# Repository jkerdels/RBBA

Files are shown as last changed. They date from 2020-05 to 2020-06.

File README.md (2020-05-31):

# RBBA
resuscitator-based breathing assistance

This project explores the idea of building a breathing assistance system based on a resuscitator, which is safe enough for actual usage. This includes the use of sensors to limit the pressure supplied to a recipient and a calibration procedure that allows the system to estimate the volume of air given. In addition, the device should be printable on affordable, low-end 3D printers and use only hardware parts that are widely available. Likewise, the electronics involved should be as minimal as possible, easy to program, and adaptable to one's needs.

## Current Status

There exists a hardware prototype including a control-box that houses all the electronics and an external pressure sensor. Furthermore, all basic software components are implemented and ready to be used for the user-end part of the code (which is still incomplete).

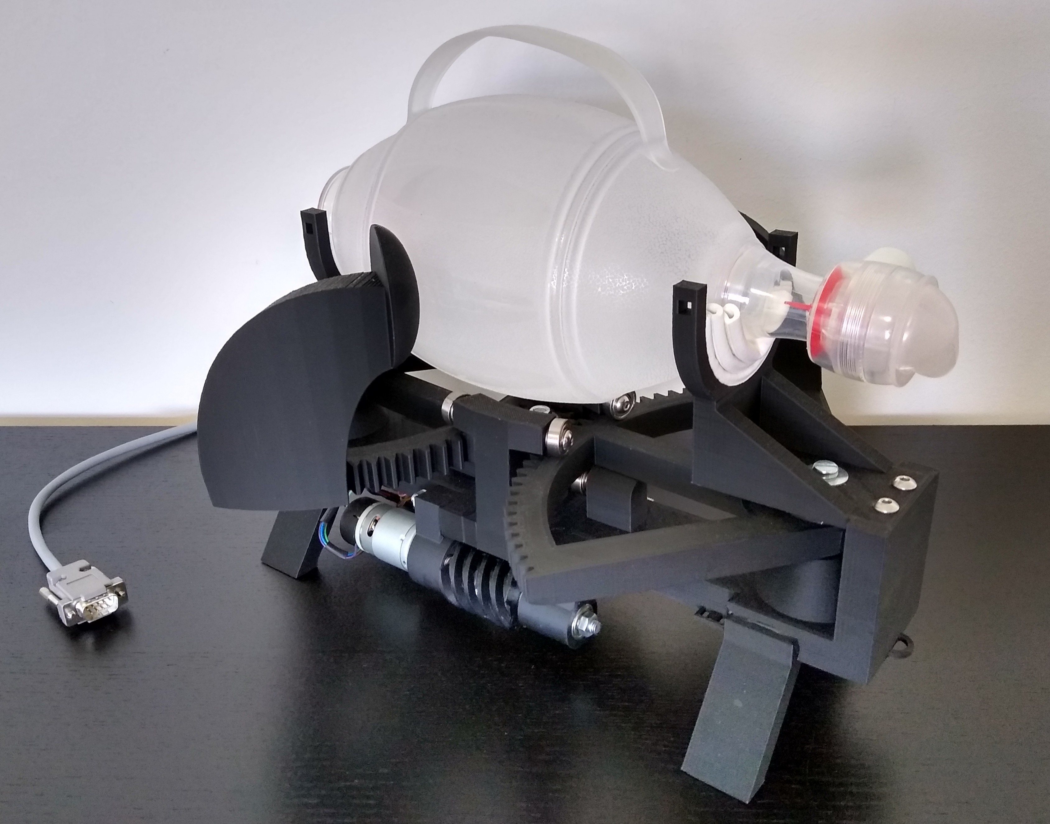
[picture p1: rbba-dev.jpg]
device_photo device prototype

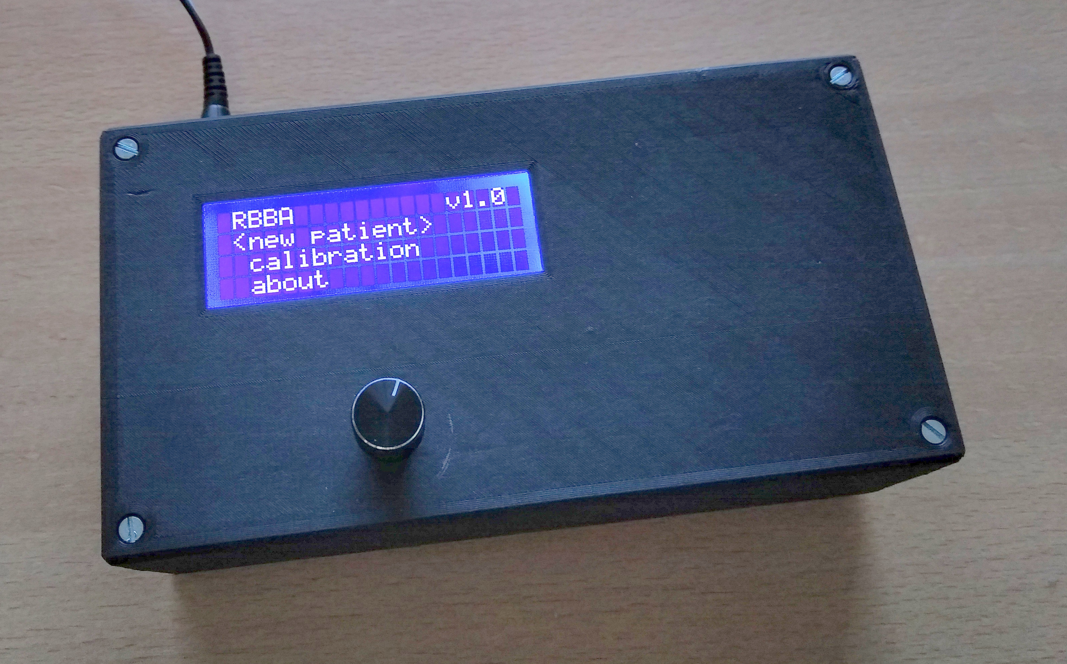
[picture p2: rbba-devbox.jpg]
controlbox_photo control box prototype

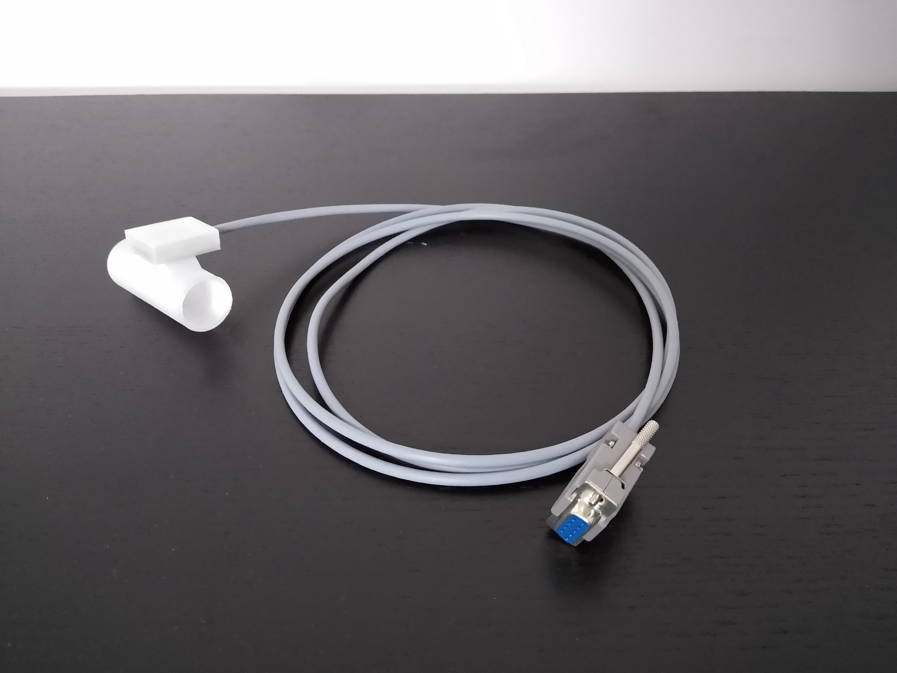
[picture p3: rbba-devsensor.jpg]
sensor_photo pressure sensor prototype


## Geometry

The geometry of the hardware was modeled in OpenSCAD. This way, it is relatively easy to adapt the geometry, e.g., to work well with a particular 3D-printer. In addition, using OpenSCAD allows to automate the generation of all stl-files via a simple command line script.

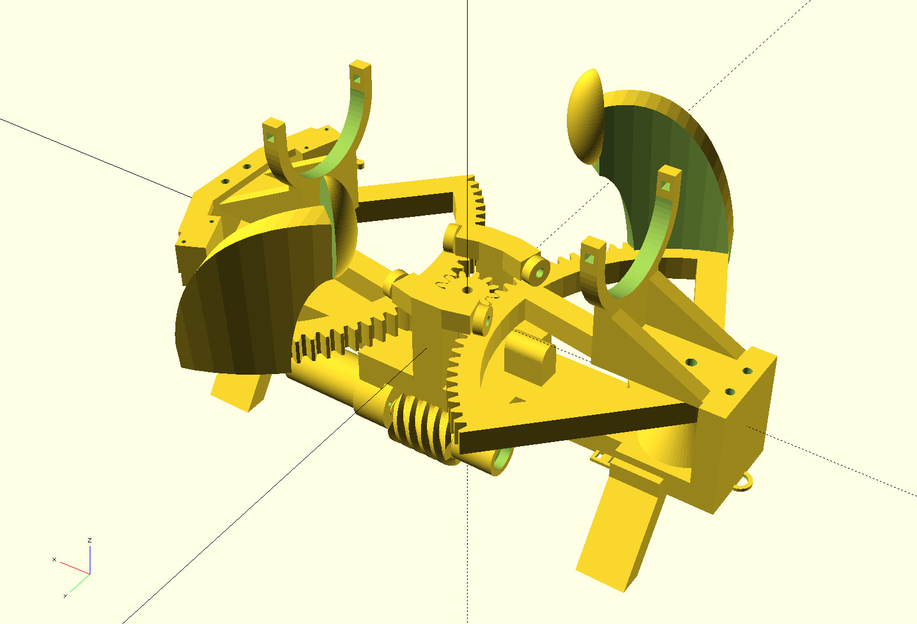
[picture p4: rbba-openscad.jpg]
parametric_geometry device geometry


## Electronics & Code

The electronics are based on the Arduino platform in order to make the code and hardware as accessible as possible. The arduino project does not rely on external libraries and brings everything with it to, e.g., read out sensors or write messages to the output display. The main board used is an Arduino Nano compatible device. Additional modules include the BMP280 pressure sensor, a L298N motor driver, a HD44780 display with an I2C-Driver (FC-113), and a rotary encoder input dial.

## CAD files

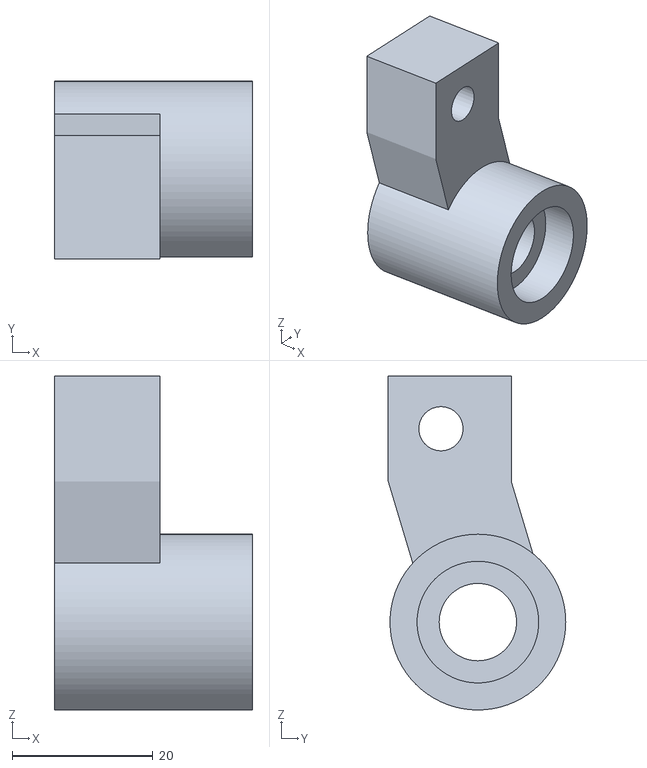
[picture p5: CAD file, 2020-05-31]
openscad/stl/wormgearmount.stl
28.2 x 25.2 x 47.5

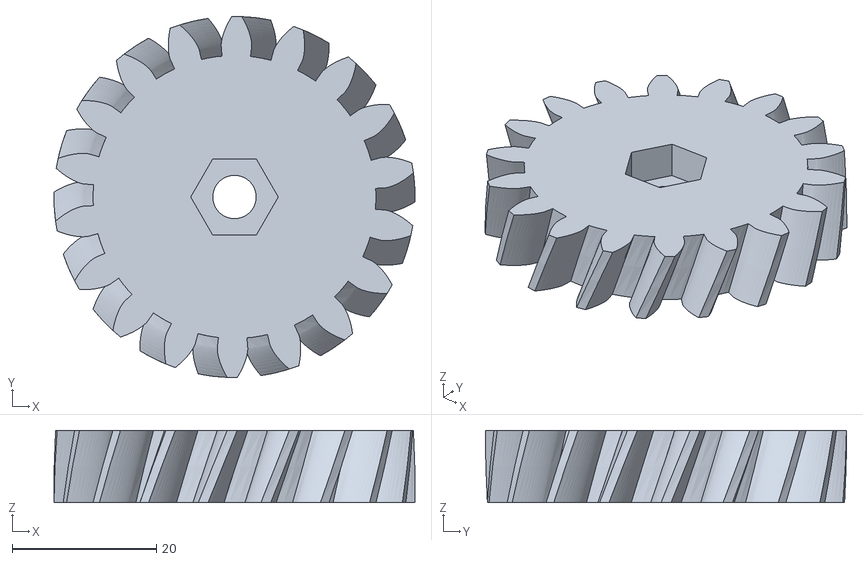
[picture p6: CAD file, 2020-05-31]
openscad/stl/motor_gear_1.stl
50.0 x 50.0 x 10.0

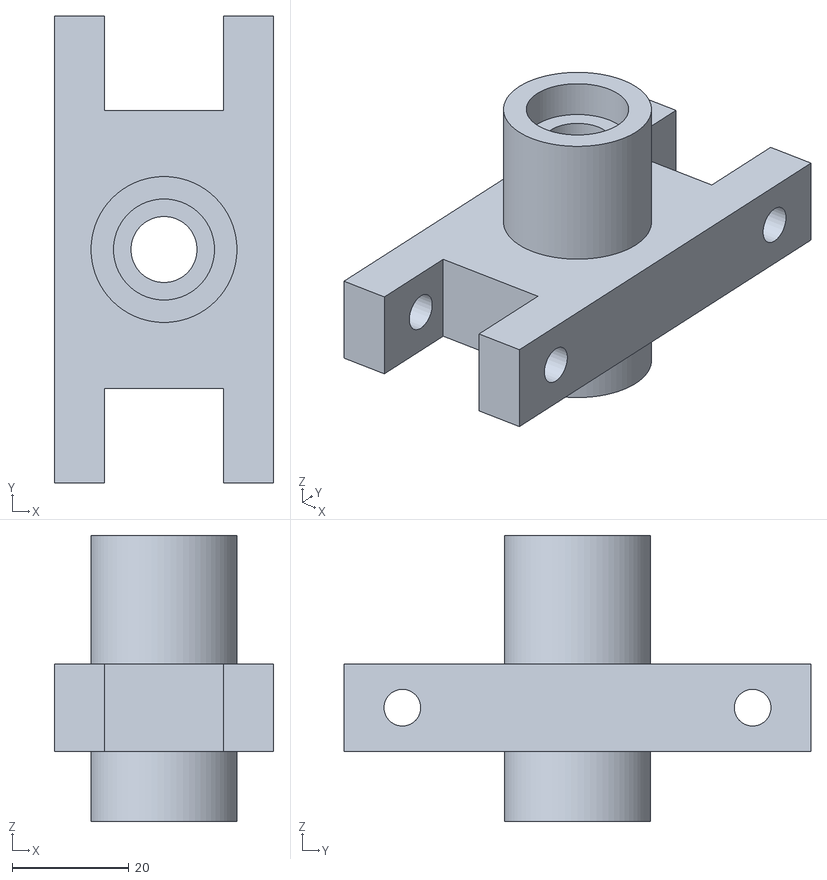
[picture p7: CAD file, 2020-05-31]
openscad/stl/centermount.stl
37.6 x 80.0 x 49.0

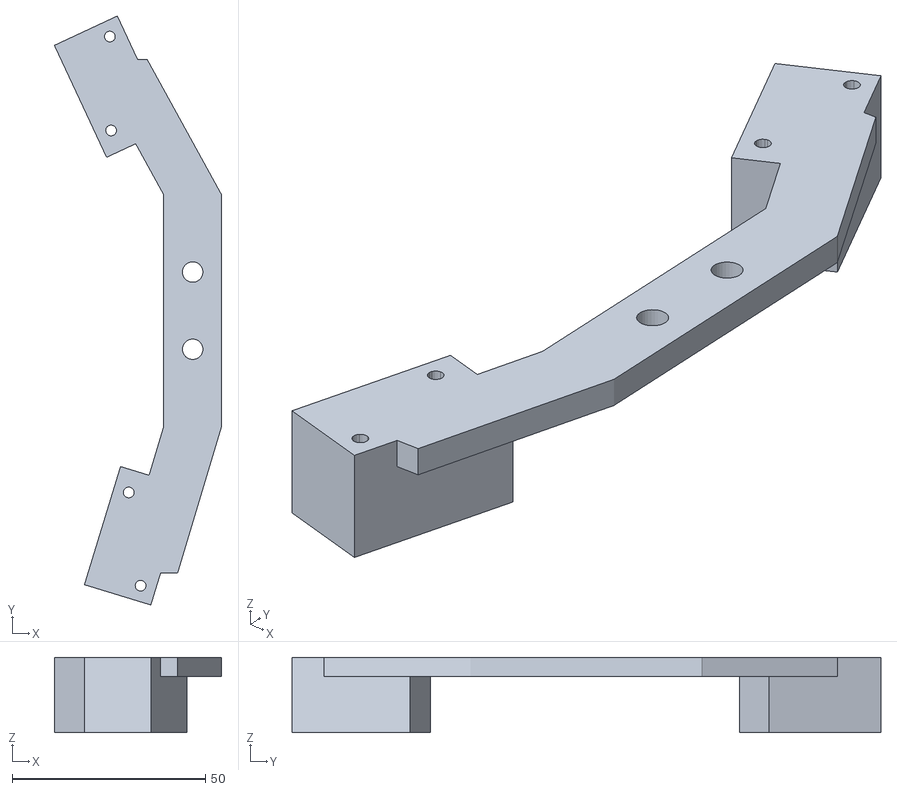
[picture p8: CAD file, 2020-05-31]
openscad/stl/switchmount.stl
43.3 x 152.6 x 19.5

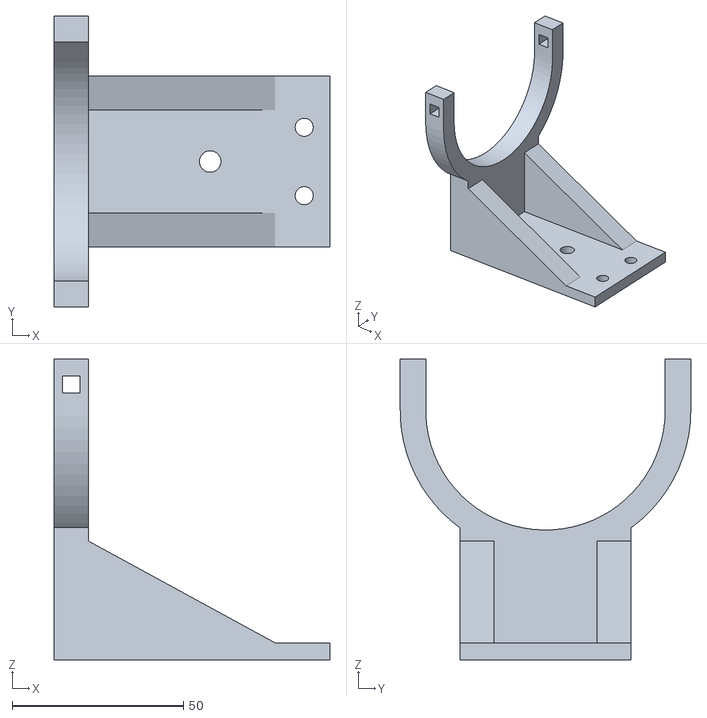
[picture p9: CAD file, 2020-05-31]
openscad/stl/bagmount.stl
80.6 x 85.0 x 88.0

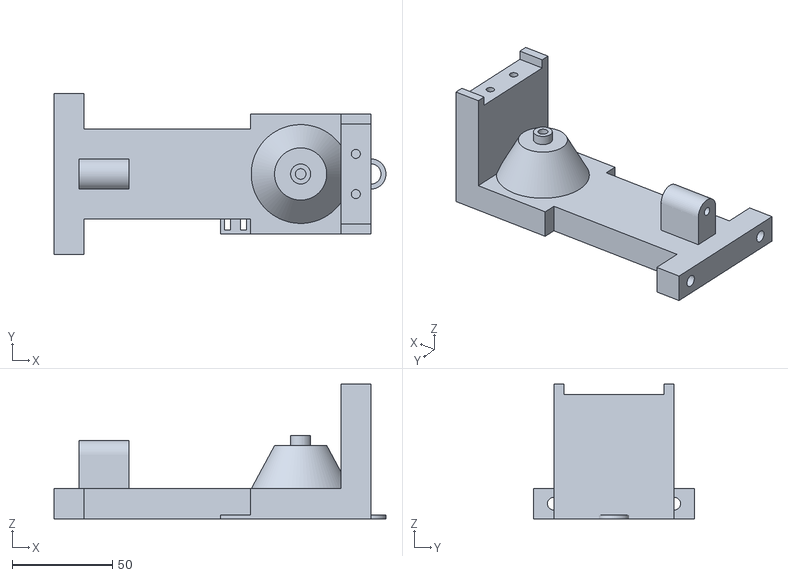
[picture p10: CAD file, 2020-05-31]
openscad/stl/gear_base.stl
165.3 x 80.0 x 67.0

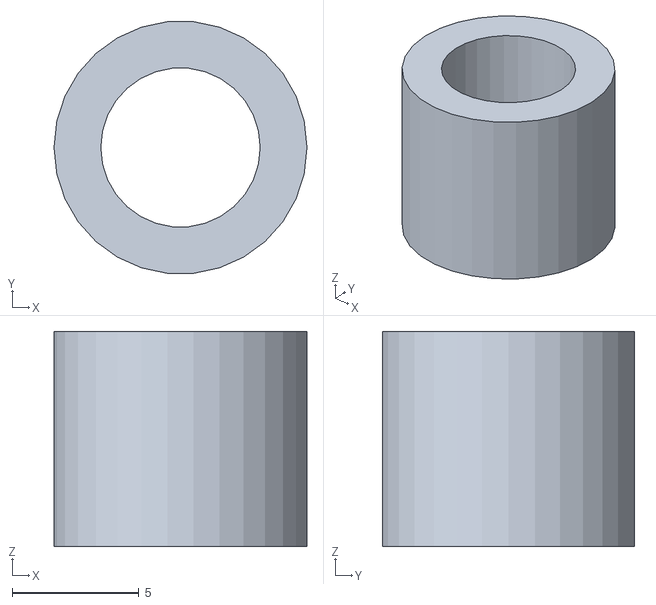
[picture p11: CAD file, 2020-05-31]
openscad/stl/bagmount_spacer.stl
10.0 x 9.95 x 8.50

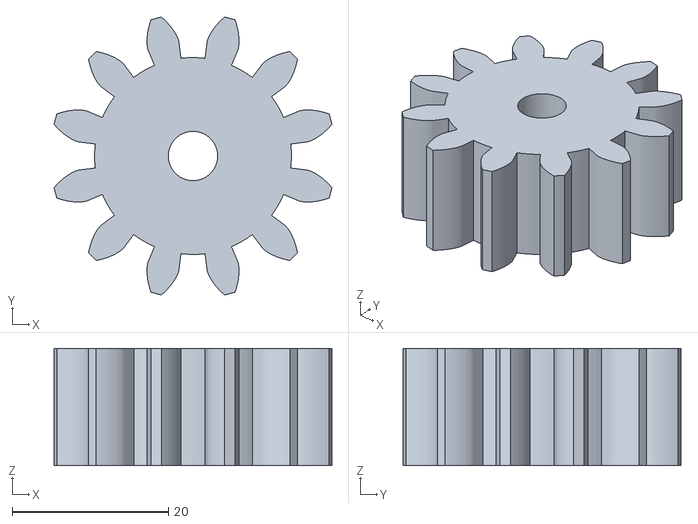
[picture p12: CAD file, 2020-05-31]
openscad/stl/drive_gear.stl
35.5 x 35.5 x 15.0

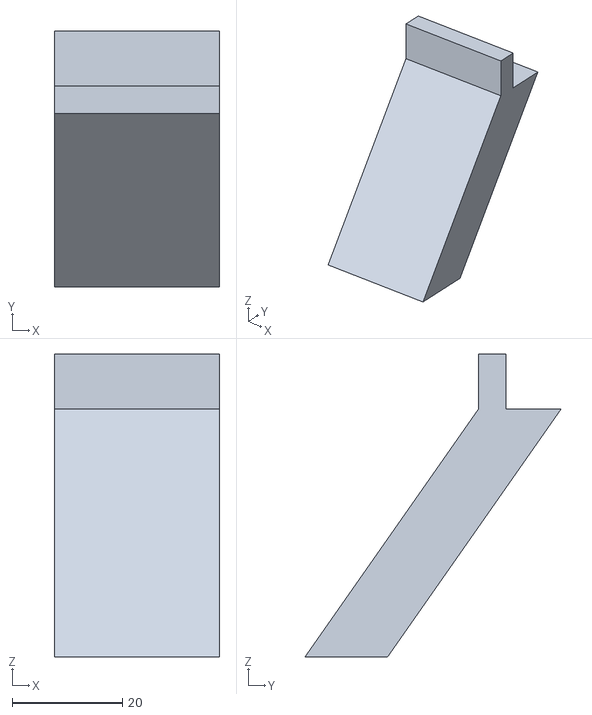
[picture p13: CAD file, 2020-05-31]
openscad/stl/leg.stl
30.0 x 46.5 x 55.0

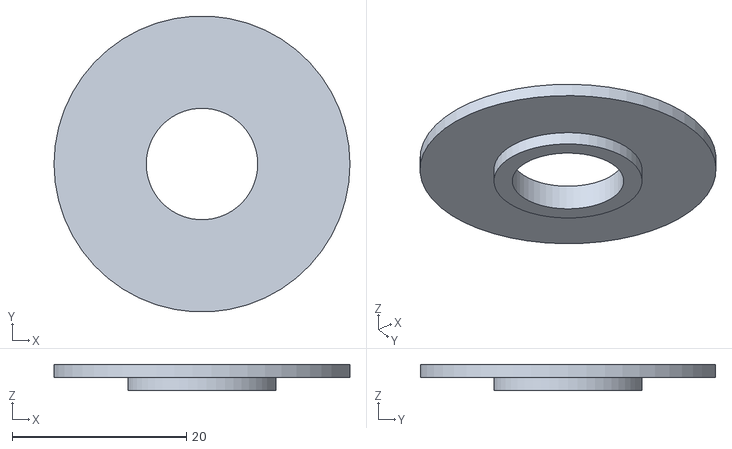
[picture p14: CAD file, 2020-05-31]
openscad/stl/gear_plug.stl
34.0 x 33.9 x 3.00

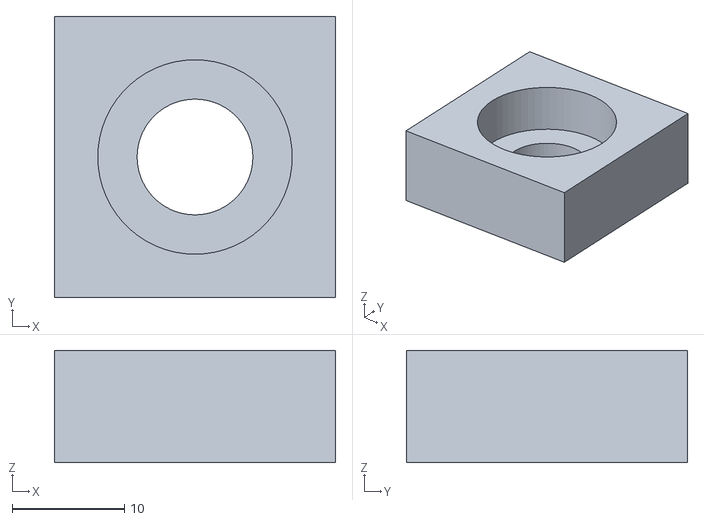
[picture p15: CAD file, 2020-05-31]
openscad/stl/calibration.stl
25.0 x 25.0 x 10.0

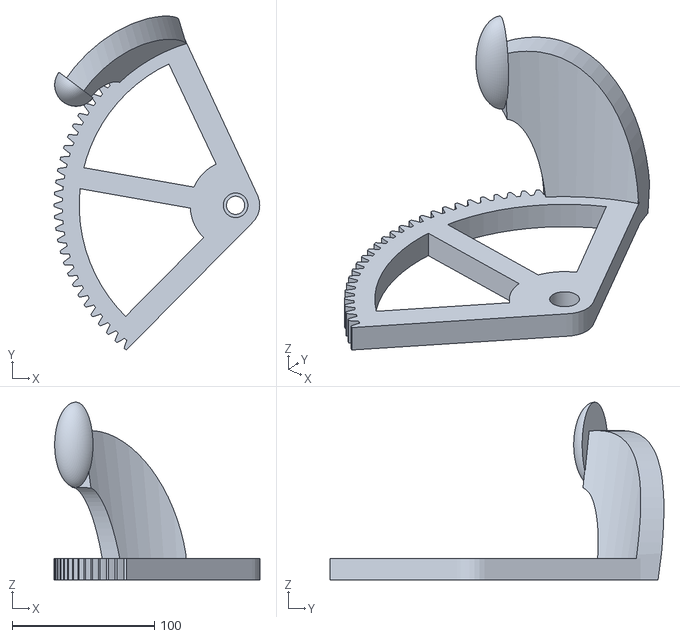
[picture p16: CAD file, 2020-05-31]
openscad/stl/gear.stl
144.6 x 235.0 x 124.9

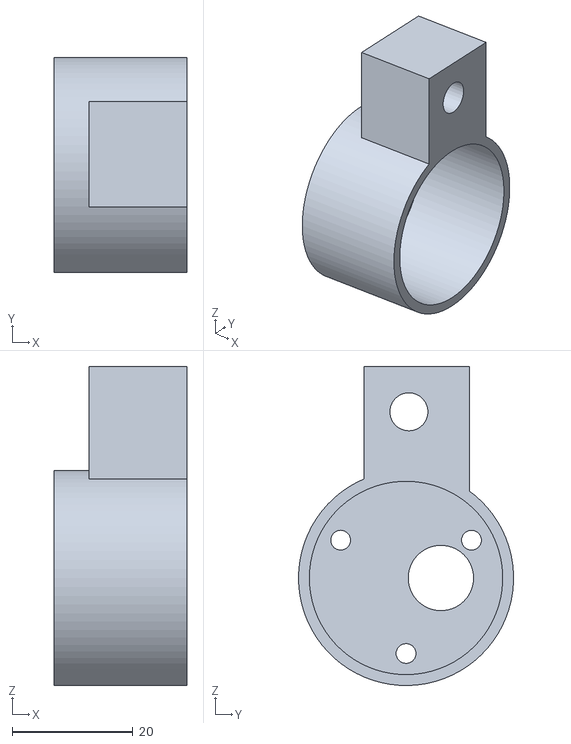
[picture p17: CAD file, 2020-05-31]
openscad/stl/motormount.stl
22.0 x 35.6 x 52.8

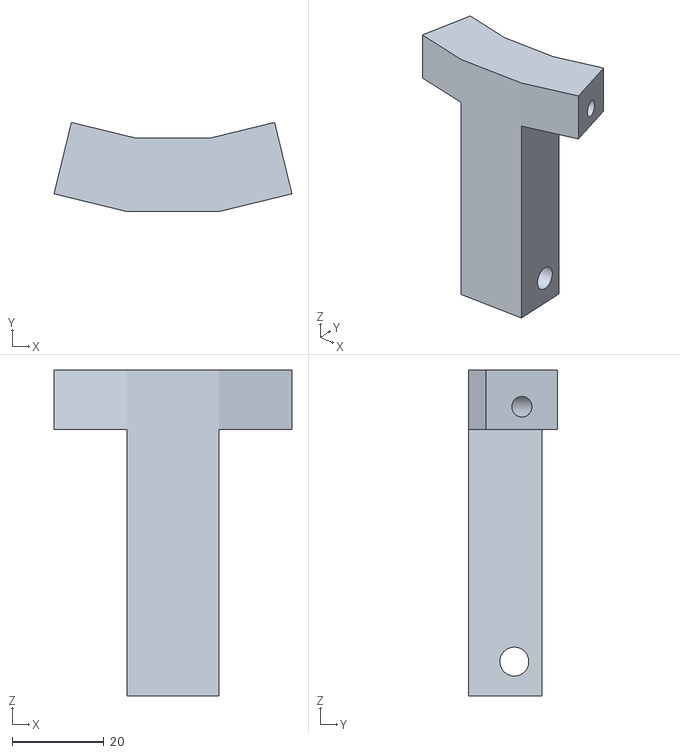
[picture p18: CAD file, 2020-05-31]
openscad/stl/bearingmount.stl
51.8 x 19.4 x 71.0

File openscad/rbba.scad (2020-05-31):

/* rbba.scad 

    3D geometry of a 3D-printable breathing assistance system that utilizes
    a standard resuscitator.
    
    The different parts can be selected via the render_ctl variable by 
    setting it to the available render_ctl options (see below). Instead,
    all parts can be rendered via the render_stl.sh script.
    
    The 3D geometry defined here uses the OpenSCAD-Library "Getriebe.scad"
    by Dr Jörg Janssen in Version 2.3 . The library is contained in the
    3rd-party folder and should be put into the library-folder of your
    OpenSCAD installation. You can find the library folder by clicking on
    "File->Show Library Folder..." in OpenSCAD.

    The device consists of three major parts: two identical outer parts
    and a center piece that may has to be adapted to the particular 
    requirements of the geared motor used.
    
    To adjust the model to your printer, the variable "hole_extra" allows
    you to tweak the size of negative shapes in the model. There is a 
    calibration piece that can be selected with render_ctl = rc_calibration;
    You should be able to put a 17mm bearing snugly into the hole of the
    calibration piece. Please adjust the hole_extra variable until that is
    the case.
    
    The bearings used here are 17mm outside diameter, 6mm inner diameter, 
    and 6mm height. If you want to use bearings with slightly different
    dimensions you can adjust the variables bearing_outer, bearing_inner,
    and bearing_height.
*/
use <Getriebe.scad>;

hole_extra = 0.3;

pr_diam   = 250;
pr_zaehne = 96;
pr_modul  = pr_diam/pr_zaehne;
pr_breite = 15;
pr_loch   = 17;

bag_dia = 130;

hole_drive = 5;
notch_drive = 4;
teeth_drive = 12;
diam_drive = pr_modul * teeth_drive;

bearing_outer  = 17;
bearing_inner  = 6;
bearing_height = 6;

bearing_offset = 0.5;

//gear_angle = 27;
gear_angle = 0;

motor_mount_width = 35.6;
motor_mount_extra = 2;

// render_ctl options: 
rc_all             = "all";
rc_calibration     = "calibration";
rc_gear            = "gear";
rc_gear_base       = "gear_base";
rc_gear_plug       = "gear_plug";
rc_drive_gear      = "drive_gear";
rc_motormount      = "motormount";
rc_bearingmount    = "bearingmount";
rc_bagmount        = "bagmount";
rc_bagmount_spacer = "bagmount_spacer";
rc_leg             = "leg";
rc_switchmount     = "switchmount";
rc_motor_gear1     = "motor_gear1";
rc_motor_gear2     = "motor_gear2";
rc_centermount     = "centermount";
rc_wormgearmount   = "wormgearmount";

render_ctl = rc_all;

module bearing() {
    color("silver")
    difference(){
        cylinder(d=bearing_outer,h=bearing_height,$fn=72);   
        translate([0,0,-1]) 
        cylinder(d=bearing_inner,h=bearing_height+2,$fn=30);
    }
}

module bearings() {    
    translate([diam_drive/2+10,0,0])
    translate([pr_diam/2-10,0,0])
    rotate([0,0,0])
    translate([-pr_diam/2+10,0,0])
    translate([-bearing_height/2,0,-bearing_outer/2])
    rotate([90,0,90])
    bearing();

    translate([pr_diam/2+diam_drive/2,0,pr_breite+bearing_outer/2])
    rotate([0,0,13.668])
    translate([-pr_diam/2,0,0])
    translate([6.5,0,0])
    rotate([90,0,90])
    bearing();

    mirror([1,0,0])
    translate([pr_diam/2+diam_drive/2,0,pr_breite+bearing_outer/2])
    rotate([0,0,13.668])
    translate([-pr_diam/2,0,0])
    translate([6.5,0,0])
    rotate([90,0,90])
    bearing();

    rotate([0,0,180]){
        translate([pr_diam/2+diam_drive/2,0,pr_breite+bearing_outer/2])
        rotate([0,0,13.668])
        translate([-pr_diam/2,0,0])
        translate([6.5,0,0])
        rotate([90,0,90])
        bearing();

        mirror([1,0,0])
        translate([pr_diam/2+diam_drive/2,0,pr_breite+bearing_outer/2])
        rotate([0,0,13.668])
        translate([-pr_diam/2,0,0])
        translate([6.5,0,0])
        rotate([90,0,90])
        bearing();
    }

    /*
    translate([diam_drive/2+10,0,0])
    translate([pr_diam/2-10,0,0])
    rotate([0,0,-30])
    translate([-pr_diam/2+10,0,0])
    translate([-bearing_height/2,0,-bearing_outer/2])
    rotate([90,0,90])
    bearing();

    translate([diam_drive/2+10,0,0])
    translate([pr_diam/2-10,0,0])
    rotate([0,0,30])
    translate([-pr_diam/2+10,0,0])
    translate([-bearing_height/2,0,-bearing_outer/2])
    rotate([90,0,90])
    bearing();
    */

}

module bag() {
    sphere(d=bag_dia,$fn=75);

    translate([0,5/2-100,0])
    rotate([90,0,0])
    cylinder(d=45,h=5);

    translate([0,5/2+90,0])
    rotate([90,0,0])
    cylinder(d=70,h=5);
}


module pusher_knob() {
    translate([0,0,0])
    rotate([0,90,0])
    difference(){
        scale([1,0.5,0.5])
        sphere(d=60,$fn=75);
        translate([-30,-30,0])
        cube([60,60,30]);        
    }    
}

module push_rod(){
    translate([0,-15/2,-30/2])
    cube([30,15,30]);

    translate([15,-15/2,-30-30/2])
    cube([15,15,30]);

    translate([15,-15/2,-85-30-30/2])
    cube([15,15,85]);
}

module drive_gear() {
        
    render()
    difference(){
        union(){
            stirnrad (pr_modul, teeth_drive, pr_breite, hole_drive+hole_extra, optimiert=false);

            rotate([0,0,180/teeth_drive])
            translate([-(hole_drive+hole_extra)/2,(hole_drive+hole_extra)/2-(hole_drive-notch_drive),0])
            cube([hole_drive+hole_extra,hole_drive+hole_extra/2,pr_breite]);
        }
        translate([0,0,-2.5])
        rotate([0,0,180/teeth_drive])
        translate([0,0,pr_breite/2]){
            rotate([270,0,0])
            cylinder(d=3+hole_extra,h=40,$fn=30);
            translate([-(5.5+hole_extra)/2,diam_drive/6,-(1.5+hole_extra)-1.8])
            cube([5.5+hole_extra,2.5+hole_extra,pr_breite/2+1.8+hole_extra+10]);
        }
    }
}

module drive_gear2() {
        
    render()
    difference(){
        union(){
            stirnrad (pr_modul, teeth_drive, pr_breite, 6+hole_extra, optimiert=false);
        }
        translate([0,0,-1])
        for(i = [0:60:359])
        rotate([0,0,i])
        translate([-(6+hole_extra-0.25)/2,-(10+hole_extra+0.2)/2,0])
        cube([6+hole_extra-0.25,10+hole_extra+0.2,5+1]);
    }
    
}

module gear_plug() {

    translate([0,0,pr_breite-1.5])
    difference(){
        cylinder(d=pr_loch,h=1.5,$fn=50);
        translate([0,0,-1])
        cylinder(d=pr_loch-4.5+hole_extra,h=3.5,$fn=50);
    }

    translate([0,0,pr_breite])
    difference(){
        cylinder(d=pr_loch*2,h=1.5,$fn=50);
        translate([0,0,-1])
        cylinder(d=pr_loch-4.5+hole_extra,h=3.5,$fn=50);
    }
    
}

module cake(angle){
    color("blue")
    difference(){
        cylinder(d=pr_diam-30,h=pr_breite+2,$fn=75);
        translate([-pr_diam/2,0,-1])
        cube([pr_diam,pr_diam/2,pr_breite+4]);
        rotate([0,0,angle])
        translate([-pr_diam/2,0,-1])
        cube([pr_diam,pr_diam/2,pr_breite+4]);
        translate([0,0,-1])
        cylinder(d=2*pr_loch+30,h=pr_breite+4,$fn=75);
    }
}

module gear(offset = false) {
    render()
    difference(){
        intersection(){
            rotate([0,0,offset ? 180/pr_zaehne : 0])
            stirnrad (pr_modul, pr_zaehne, pr_breite, pr_loch+hole_extra, optimiert=false);

            translate([0,0,-1])
            linear_extrude(height=pr_breite*2)
            minkowski(){
                union(){
                    rotate([0,0,115])
                    square([pr_diam/2+10,pr_diam/2+10]);
                    rotate([0,0,135.3])
                    square([pr_diam/2+10,pr_diam/2+10]);
                }
                circle(d=pr_loch*2);
            }
        }    
        translate([0,0,-1])
        rotate([0,0,135.3+90])
        cake(70);
    }
    
    rotate([0,0,170])
    translate([10,-15/2,0])
    cube([pr_diam/2-20,15,pr_breite]);
    
    difference(){
        cylinder(d=pr_loch+1,h=1.5,$fn=50);
        translate([0,0,-1])
        cylinder(d=pr_loch-4.5+hole_extra,h=3.5,$fn=50);
    }

    difference(){
        intersection(){
            difference(){
                translate([0,0,0])
                cylinder(d1=pr_diam+5+15,d2=pr_diam+5+15+diam_drive/2+13,h=bag_dia/2+5+20+pr_breite,$fn=75);

                translate([0,0,-1])
                cylinder(d1=pr_diam+5-30+7.5,d2=pr_diam+5-30+7.5+diam_drive/2+20,h=bag_dia/2+5+20+pr_breite+2,$fn=75);
                
                rotate([0,0,180-36.8])
                translate([-(pr_diam+50+diam_drive)/2,0,-1])
                cube([pr_diam+50+diam_drive,pr_diam/2+50+diam_drive,bag_dia/2+5+20+pr_breite+2]);

                rotate([0,0,287])
                translate([-(pr_diam+50+diam_drive)/2,0,-1])
                cube([pr_diam+50+diam_drive,pr_diam/2+50+diam_drive,bag_dia/2+5+20+pr_breite+2]);
            }    
            rotate([0,0,16.5])
            scale([0.7,1,1])
            translate([-105,0,0])
            rotate([270,0,0])
            cylinder(d=210,h=150,$fn=75);
        }
        rotate([0,0,43])
        scale([0.5,1,1.3])
        translate([-50,0,0])
        rotate([270,0,0])
        cylinder(d=100,h=150,$fn=75);
    }
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

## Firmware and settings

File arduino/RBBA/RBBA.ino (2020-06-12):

/* Overview:

This is the main file for the arduino part of the RBBA project.

To build your own RBBA it is not strictly necessary to have all the
exact same electronic parts as they are used here, i.e., this arduino
project serves more as an example of how one might control the device.

For all components that are used in this example code I did not use
any libraries but implemented everything from scratch. This had multiple
purposes: 1) If you use code in a medical device you should be familiar
with the code and the devices you use as much as possible. Using libraries
and electronic components "black box style" is (in my opinion) not a
good choice in that case. 2) You minimize dependencies on 3rd-party code
a lot, which makes the code much more self-contained and easier to use
for others. 3) There is an educational aspect in both writing the 
libraries myself and "seeing" that the apparent complexity of an 
electronic project with many components, different protocols, etc. is
actually manageable and not as hard as one might think.

This style starts with a configuration section where you can map the
pins used on your arduino board to the different components like the
motor controller or the encoder of the motor. Most pins used are general
purpose digital IO-pins. If the pin has to have some special abilities
it is noted via a comment.

Following the configuration section is an implementation section where
the different components of the program are instantiated as global
variables. Part of this section is the instantiation/definition of 
the user menu and multiple state machines that define the behavior
of the system. Both constructs make use of rather modern C++, e.g.,
using lambda functions to construct menu pages or define the code
that is run in a given state. This might seem a bit over-engineered
and a number of people will prefer the more simpler or "proven" approach
of switch-based state machines.

Finally, the arduino-typical setup and loop functions do little more
than putting all the previously defined puzzle-pieces together.

*/

#include <stdint.h>
#include <EEPROM.h>
#include "encoder.h"
#include "motor_control.h"
#include "soft_bmp280.h"
#include "soft_hd44780.h"
#include "lcd_menu.h"
#include "text_buffer.h"
#include "state_machine.h"
#include "string_constants.h"

// configuration
const uint8_t motor_enable_pin      = 3; // OC2B of timer2
const uint8_t motor_direction_pin_A = 4;
const uint8_t motor_direction_pin_B = 5;
const uint8_t end_stop_opened_pin   = 7;
const uint8_t end_stop_closed_pin   = 8;
const uint8_t motor_encoder_pin_A   = 2; // needs to be on an interrupt pin
const uint8_t motor_encoder_pin_B   = 6;

const uint8_t control_loop_delay = 20;

const uint8_t p1_slave_address = 0x77;
const uint8_t p1_scl_pin       = A0;
const uint8_t p1_sda_pin       = A1;
const uint8_t p1_speed_khz     = 200;

const uint8_t lcd_slave_address = 0x27;
const uint8_t lcd_scl_pin       = 11;
const uint8_t lcd_sda_pin       = 12;
const uint8_t lcd_speed_khz     = 100;

const uint8_t knob_encoder_pin_A = A4;
const uint8_t knob_encoder_pin_B = A3;
const uint8_t knob_push_pin      = A5;

// implementation

// encoder of the motor
Encoder encoder(motor_encoder_pin_A, motor_encoder_pin_B);

// L298N-based motor control
MotorControl mc(
  motor_enable_pin,
  motor_direction_pin_A,
  motor_direction_pin_B,
  end_stop_opened_pin,
  end_stop_closed_pin,
  (uint16_t)control_loop_delay*(uint16_t)1000,
  encoder
);

// pressure sensor 1 input
SoftBMP280 p1(p1_slave_address,p1_scl_pin,p1_sda_pin,p1_speed_khz);

// LCD display output
SoftHD44780 lcd(lcd_slave_address,lcd_scl_pin,lcd_sda_pin,lcd_speed_khz);

// encoder of the control knob that is used as user interface of the device
Encoder knob_encoder(knob_encoder_pin_A, knob_encoder_pin_B);

// global state textbuffer (used in the UI)
TextBufferImpl<20> tbuf;

// default patient height
uint8_t patient_height_cm = 175;

// array that contains the volume calibration data of the resuscitator used
uint16_t bag_vol_calib_data[9];

// some state variables that control program flow
bool run_motor_encoder_calibration = false;
int16_t mc_calibrate_enc = 0;

bool run_bag_volume_calibration = false;
uint8_t bag_vol_calib_step = 1;
bool bag_vol_calib_step_go = false;
uint16_t bag_vol_value = 0;
bool bag_vol_calib_next = false;


// EEPROM config storage and loading
void store_calibration() {
  mc_calibrate_enc = mc.get_max_encoder();
  EEPROM.put(0,mc_calibrate_enc);
  for(uint8_t i = 0; i < 9; ++i) {
    uint16_t tmp = bag_vol_calib_data[i];
    EEPROM.put(2+i*2,tmp);
  }
}

void load_calibration() {
  EEPROM.get(0,mc_calibrate_enc);
  mc.set_max_encoder(mc_calibrate_enc);
  for(uint8_t i = 0; i < 9; ++i) {
    uint16_t tmp;
    EEPROM.get(2+i*2,tmp);
    bag_vol_calib_data[i] = tmp;
  }  
}


enum class panel_id : uint8_t {
  MAIN_SCREEN,
  NEW_PATIENT_CONFIG,
  CALIBRATION_MAIN,
  ABOUT,
  ENCODER_CAL,
  BAG_CAL_1,
  BAG_CAL_2
};

// setting up menu
auto lcd_menu = make_menu(
  lcd,
  knob_encoder,
  knob_push_pin,
  panel_id::MAIN_SCREEN,
  // panel 0, main panel
  Panel<panel_id>({ 
    panel_id::MAIN_SCREEN,
    [](){
      return make_panel<panel_id>( 
        new LCDMenuTextElement<panel_id>(1,0,str_RBBA),
        new LCDMenuTextElement<panel_id>(15,0,str_v10),
        new LCDMenuTextElement<panel_id>(2,1,str_nPatient,[](LCDMenuBase<panel_id> *menu, LCDMenuElement<panel_id> *element){
          menu->switch_to_panel(panel_id::NEW_PATIENT_CONFIG);
        }),
        new LCDMenuTextElement<panel_id>(2,2,str_Calibration,[](LCDMenuBase<panel_id> *menu, LCDMenuElement<panel_id> *element){
          menu->switch_to_panel(panel_id::CALIBRATION_MAIN);
        }),
        new LCDMenuTextElement<panel_id>(2,3,str_About,[](LCDMenuBase<panel_id> *menu, LCDMenuElement<panel_id> *element){
          menu->switch_to_panel(panel_id::ABOUT);
        })
      );
    }
  }),
  // panel 1, new patient config
  Panel<panel_id>({ 
    panel_id::NEW_PATIENT_CONFIG,
    [](){
      return make_panel<panel_id>( 
        new LCDMenuTextElement<panel_id>(0,0,str_patient_data),
        new LCDMenuIntElement<panel_id,uint8_t,3,0>(1,1,&patient_height_cm,str_cm,8,true,110,855),
        new LCDMenuTextElement<panel_id>(14,3,str_back,[](LCDMenuBase<panel_id> *menu, LCDMenuElement<panel_id> *element){
          menu->switch_to_panel(panel_id::MAIN_SCREEN);
        })
      );
    }
  }),
  // panel 2, calibration
  Panel<panel_id>({ 
    panel_id::CALIBRATION_MAIN,
    [](){
      return make_panel<panel_id>( 
        new LCDMenuTextElement<panel_id>(0,0,str_calibration),
        new LCDMenuTextElement<panel_id>(2,1,str_motor_encoder,[](LCDMenuBase<panel_id> *menu, LCDMenuElement<panel_id> *element){
          run_motor_encoder_calibration = true;
          menu->switch_to_panel(panel_id::ENCODER_CAL);
        }),
        new LCDMenuTextElement<panel_id>(2,2,str_bag_volume,[](LCDMenuBase<panel_id> *menu, LCDMenuElement<panel_id> *element){
          run_bag_volume_calibration = true;
          menu->switch_to_panel(panel_id::BAG_CAL_1);
        }),
        new LCDMenuTextElement<panel_id>(14,3,str_back,[](LCDMenuBase<panel_id> *menu, LCDMenuElement<panel_id> *element){
          menu->switch_to_panel(panel_id::MAIN_SCREEN);
        })
      );
    }
  }),
  // panel 3, about
  Panel<panel_id>({ 
    panel_id::ABOUT,  
    [](){
      return make_panel<panel_id>( 
        new LCDMenuTextElement<panel_id>(0,0,str_RBBA_about),
        new LCDMenuIntElement<panel_id,uint16_t,3,0>(0,1,bag_vol_calib_data,str_comma),
        new LCDMenuIntElement<panel_id,uint16_t,3,0>(4,1,bag_vol_calib_data+1,str_comma),
        new LCDMenuIntElement<panel_id,uint16_t,3,0>(8,1,bag_vol_calib_data+2,str_comma),
        new LCDMenuIntElement<panel_id,uint16_t,3,0>(12,1,bag_vol_calib_data+3,str_comma),
        new LCDMenuIntElement<panel_id,uint16_t,3,0>(16,1,bag_vol_calib_data+4,str_comma),
        new LCDMenuIntElement<panel_id,uint16_t,3,0>(0,2,bag_vol_calib_data+5,str_comma),
        new LCDMenuIntElement<panel_id,uint16_t,3,0>(4,2,bag_vol_calib_data+6,str_comma),
        new LCDMenuIntElement<panel_id,uint16_t,3,0>(8,2,bag_vol_calib_data+7,str_comma),
        new LCDMenuIntElement<panel_id,uint16_t,3,0>(12,2,bag_vol_calib_data+8,str_empty),
        new LCDMenuIntElement<panel_id,int16_t,3,0>(0,3,&mc_calibrate_enc,str_empty),
        new LCDMenuTextElement<panel_id>(14,3,str_back,[](LCDMenuBase<panel_id> *menu, LCDMenuElement<panel_id> *element){
          menu->switch_to_panel(panel_id::MAIN_SCREEN);
        })
      );
    }
  }),
  // panel 4, encoder calibration
  Panel<panel_id>({ 
    panel_id::ENCODER_CAL,
    [](){
      return make_panel<panel_id>( 
        new LCDMenuBufferElement<panel_id>(0,0,tbuf.get_buffer()),
        new LCDMenuTextElement<panel_id>(0,1,str_max_enc),
        new LCDMenuIntElement<panel_id,int16_t,5,0>(9,1,&mc_calibrate_enc,str_empty,8),
        new LCDMenuTextElement<panel_id>(14,3,str_back,[](LCDMenuBase<panel_id> *menu, LCDMenuElement<panel_id> *element){
          if (run_motor_encoder_calibration == false)
            menu->switch_to_panel(panel_id::CALIBRATION_MAIN);
        })
      );
    }
  }),
  // panel 5, bag calibration 1/2
  Panel<panel_id>({ 
    panel_id::BAG_CAL_1,
    [](){
      return make_panel<panel_id>( 
        new LCDMenuTextElement<panel_id>(0,0,str_bag_vol_calib),
        new LCDMenuTextElement<panel_id>(0,2,str_Step),
        new LCDMenuIntElement<panel_id,uint8_t,1,0>(6,2,&bag_vol_calib_step,str_of_nine,8),
        new LCDMenuTextElement<panel_id>(12,2,str_go,[](LCDMenuBase<panel_id> *menu, LCDMenuElement<panel_id> *element){
          bag_vol_calib_step_go = true;
        })
      );
    }
  }),
  // panel 6, bag calibration 2/2
  Panel<panel_id>({ 
    panel_id::BAG_CAL_2,
    [](){
      return make_panel<panel_id>( 
        new LCDMenuTextElement<panel_id>(0,0,str_bag_vol_calib),
        new LCDMenuTextElement<panel_id>(0,2,str_enter_vol), 
        new LCDMenuIntElement<panel_id,uint16_t,4,0>(12,2,&bag_vol_value,str_ml,8,true,0,1000),
        new LCDMenuTextElement<panel_id>(10,3,str_ok,[](LCDMenuBase<panel_id> *menu, LCDMenuElement<panel_id> *element){
          bag_vol_calib_next = true;
        })
      );
    }
  })
);




// state machines
uint16_t mc_calibrate_dtime;

enum class mc_calibrate_state : uint8_t {
  start,
  clear_endswitch,
  move_home,
  move_max,
  finish,
  return_
};

auto mc_calibrate = make_state_machine(
  mc_calibrate_state::start,
  mc_calibrate_state::return_,

  make_state( mc_calibrate_state::start,  
  []() -> mc_calibrate_state {
    tbuf.put("moving to min");
    if (mc.open_end_stop()) {
      mc_calibrate_dtime = millis() & (uint32_t)1023;
      mc.move_raw(mc.home_PWM,1);
      return mc_calibrate_state::clear_endswitch;
    }
    return mc_calibrate_state::move_home;
  }),
  
  make_state( mc_calibrate_state::clear_endswitch,
  []() -> mc_calibrate_state {
    if (mc.open_end_stop())
      return mc_calibrate_state::clear_endswitch;
    uint16_t now = millis() & (uint32_t)1023;
    if (((now + 1024 - mc_calibrate_dtime) & 1023) > 200)
      return mc_calibrate_state::move_home;
    return mc_calibrate_state::clear_endswitch;
  }),

  make_state( mc_calibrate_state::move_home,
  []() -> mc_calibrate_state {
    mc.move_raw(mc.home_PWM,0);
    return mc_calibrate_state::move_max;
  }),
  
  make_state( mc_calibrate_state::move_max,
  []() -> mc_calibrate_state {
    if (mc.open_end_stop()) {
      tbuf.put("moving to max");
      mc.hard_stop();
      mc.zero_enc();
      mc_calibrate_enc = 0;
      mc.move_raw(mc.home_PWM,1);
      return mc_calibrate_state::finish;
    }
    return mc_calibrate_state::move_max;
  }),

  make_state( mc_calibrate_state::finish,
  []() -> mc_calibrate_state {
    mc_calibrate_enc = mc.get_encoder_value();
    if (mc.close_end_stop()) {
      tbuf.put("encoder cal done");
      mc.hard_stop();
      mc.max_enc();
      mc.move_const_speed(10,100);
      return mc_calibrate_state::return_;
    }
    return mc_calibrate_state::finish;
  })
);





enum class bag_calib_state : uint8_t {
  start,
  begin_step,
  end_step,
  return_
};

auto bag_calibrate = make_state_machine(
  bag_calib_state::start,
  bag_calib_state::return_,

  make_state( bag_calib_state::start,  
  []() -> bag_calib_state {
    bag_vol_calib_step = 1;
    bag_vol_value = 0;
    bag_vol_calib_step_go = false;
    bag_vol_calib_next = false;
    return bag_calib_state::begin_step;
  }),

  make_state( bag_calib_state::begin_step,  
  []() -> bag_calib_state {
    if (bag_vol_calib_step_go) {
      bag_vol_calib_step_go = false;
      lcd_menu.switch_to_panel(panel_id::BAG_CAL_2);
      mc.move_const_speed(10+bag_vol_calib_step*10,75);
      return bag_calib_state::end_step;
    }
    return bag_calib_state::begin_step;
  }),

  make_state( bag_calib_state::end_step,  
  []() -> bag_calib_state {
    if (bag_vol_calib_next) {
      bag_vol_calib_next = false;
      bag_vol_calib_data[bag_vol_calib_step-1] = bag_vol_value;
      if (bag_vol_calib_step < 9) {
        ++bag_vol_calib_step;
        lcd_menu.switch_to_panel(panel_id::BAG_CAL_1);
        mc.move_const_speed(10,75);
        return bag_calib_state::begin_step;
      }
      mc.move_const_speed(10,75);
      lcd_menu.switch_to_panel(panel_id::CALIBRATION_MAIN);
      return bag_calib_state::return_;
    }
    return bag_calib_state::end_step;
  })

);




ISR(PCINT1_vect)
{
  knob_encoder.update();
}


void setup() {
//  Serial.begin(115200);
  
  lcd.init();
  
  lcd.set_cursor(0,0);
  lcd.print("Initializing...");

  delay(1000);

  // attach encoder update to interrupt
  attachInterrupt(digitalPinToInterrupt(motor_encoder_pin_A),[](){encoder.update();},CHANGE);

  // attach knob encoder to interrupt (the avr way)
  PCICR  |= 2;
  PCMSK1 |= 16; // pin PC4 aka A4

  lcd.set_cursor(0,1);
  lcd.print("p1 init");
  // calibrate pressure sensor
  p1.load_calibration();
  
  // configure pressure sensor
  p1.set_temp_oversampling(SoftBMP280::Oversampling::x1);
  p1.set_pressure_oversampling(SoftBMP280::Oversampling::x4);
  p1.set_filter_coeff(SoftBMP280::FilterCoeff::off);
  p1.set_standby_time(SoftBMP280::StandbyTime::ms0_5);
  
  p1.set_mode(SoftBMP280::Mode::normal);

  load_calibration();

  // setting up timer1 for the main loop
  // in normal mode
  TCCR1A = 0;
  TCCR1B = 3; // prescaler of 64 -> 250 ticks per millisecond
  TCCR1C = 0;  
}

const uint16_t ticks_per_ms = 250;

uint8_t tmpcnt = 0;

void loop() {
  
  TCNT1 = 0;
  
  mc.update(); // measured as 15 ticks -> 60uS

  // lets make this first slot 100uS then (4uS per tick)
  while(TCNT1 < 100 / 4);

  p1.read_sensor_data();

  // this slot neets to be 1000 ticks long (4ms)
  while(TCNT1 < 1000);

  if ((run_motor_encoder_calibration) && (mc_calibrate.execute_step())) {
    run_motor_encoder_calibration = false;
    store_calibration();
  }

  if ((run_bag_volume_calibration) && (bag_calibrate.execute_step())) {
    run_bag_volume_calibration = false;
    store_calibration();
  }

  lcd_menu.update();
    
  while(TCNT1 < (const uint16_t)control_loop_delay * ticks_per_ms);

}

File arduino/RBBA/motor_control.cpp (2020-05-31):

#include <Arduino.h>
#include "encoder.h"
#include "motor_control.h"

MotorControl::MotorControl(    
  const uint8_t   en_pin, 
  const uint8_t   dir_pin_A, 
  const uint8_t   dir_pin_B,
  const uint8_t   es_opened_pin,
  const uint8_t   es_closed_pin,
  const uint16_t  upd_interval_uS,
  Encoder  &enc
) :
  motor_enable_pin(en_pin),
  motor_direction_pin_A(dir_pin_A),
  motor_direction_pin_B(dir_pin_B),
  end_stop_opened_pin(es_opened_pin),
  end_stop_closed_pin(es_closed_pin),
  update_interval_uS(upd_interval_uS),
  encoder(enc),
  last_encoder_value(0),
  set_speed(0),
  cur_PWM(0),
  cur_dir(1),
  set_position(0),
  max_speed(0),
  max_enc_value(0),
  raw_mode(false)
{
  pinMode(motor_enable_pin,OUTPUT);
  digitalWrite(motor_enable_pin,LOW);
  pinMode(motor_direction_pin_A,OUTPUT);
  digitalWrite(motor_direction_pin_A,LOW);
  pinMode(motor_direction_pin_B,OUTPUT);
  digitalWrite(motor_direction_pin_B,HIGH);

  // end switches
  pinMode(end_stop_opened_pin,INPUT_PULLUP);
  pinMode(end_stop_closed_pin,INPUT_PULLUP);

  // setup timer2 to get rid of the awful 1khz noise of analogWrite
#ifdef USE_TIMER2_OC2B  
  PRR &= ~(1 << 6);
  OCR2B = 0;
  TCCR2A = 1 << 5 | 1;
  TCCR2B = 1; // prescaler of 1
#endif    
}

void MotorControl::set_pwm(const uint8_t pwm)
{
#ifdef USE_TIMER2_OC2B    
    OCR2B = pwm;
#else    
    analogWrite(motor_enable_pin,pwm);
#endif        
}

void MotorControl::set_direction(const uint8_t dir)
{
  set_pwm(0);
  if (dir == direction_reversal) {
    digitalWrite(motor_direction_pin_A,HIGH);
    digitalWrite(motor_direction_pin_B,LOW);
  } else {
    digitalWrite(motor_direction_pin_A,LOW);
    digitalWrite(motor_direction_pin_B,HIGH);
  }
  cur_dir = dir;
}

void MotorControl::move_raw(const uint8_t pwm, const uint8_t dir)
{
  raw_mode = true;
  set_direction(dir);
  set_pwm(pwm);
}

uint8_t MotorControl::get_direction() const
{
  return cur_dir;
}

void MotorControl::hard_stop()
{
  raw_mode = false;
  set_pwm(0);
  cur_PWM   = 0;
  set_speed = 0;
  last_encoder_value = encoder.get_value() * (int16_t)encoder_reversal;
}

void MotorControl::home()
{
  if (digitalRead(end_stop_opened_pin) == LOW) {
    set_direction(1);
    set_pwm(home_PWM);
    while (digitalRead(end_stop_opened_pin) == LOW);
    delay(200);
  }
  set_direction(0);
  set_pwm(home_PWM);
  while (digitalRead(end_stop_opened_pin));
  hard_stop();
  encoder.set_value(0);    
  last_encoder_value = 0;
}

void MotorControl::calibrate()
{
  if (digitalRead(end_stop_opened_pin) == LOW) {
    set_direction(1);
    set_pwm(home_PWM);
    while (digitalRead(end_stop_opened_pin) == LOW);
    delay(200);
  }
  set_direction(0);
  set_pwm(home_PWM);
  while (digitalRead(end_stop_opened_pin));
  hard_stop();
  encoder.set_value(0);
  last_encoder_value = 0;
  set_direction(1);
  set_pwm(home_PWM);
  while (digitalRead(end_stop_closed_pin));
  hard_stop();
  max_enc_value = encoder.get_value() * (int16_t)encoder_reversal;
  last_encoder_value = max_enc_value;
}

void MotorControl::move_const_time(const uint8_t pos, const uint16_t duration_mS)
{
  set_position         = (int32_t)max_enc_value * (int32_t)pos / (int32_t)100;
  int16_t cur_position = encoder.get_value() * (int16_t)encoder_reversal;
  max_speed            = (int32_t)abs(set_position - cur_position) * (int32_t)1000 / (int32_t)duration_mS;
}

void MotorControl::move_const_speed(const uint8_t pos, const uint8_t speed)
{
  set_position         = (int32_t)max_enc_value * (int32_t)pos / (int32_t)100;
  max_speed            = (int32_t)max_enc_value * (int32_t)speed / (int32_t)100;
}

void MotorControl::update() 
{
  if (raw_mode)
    return;
  // position control section
  int16_t cur_enc_value = encoder.get_value() * (int16_t)encoder_reversal;
  int16_t cur_delta = set_position - cur_enc_value;

  if (abs(cur_delta) < position_epsilon) {
    cur_delta = 0;
  }

  set_speed = cur_delta * position_p;
  if (set_speed >  max_speed) set_speed =  max_speed;
  if (set_speed < -max_speed) set_speed = -max_speed;
  
  // speed control section
  cur_delta = cur_enc_value - last_encoder_value;

  // speed in encoder ticks per second
  int16_t cur_speed = (int16_t)((int32_t)1000000 / (int32_t)update_interval_uS) * cur_delta;
  
  int16_t speed_delta = set_speed - cur_speed;

  cur_PWM += speed_delta * (int16_t)speed_p / (int16_t)4;

  const int16_t k = 32;
  if (cur_PWM >  (int16_t)255*k) cur_PWM =  (int16_t)255*k;
  if (cur_PWM < (int16_t)-255*k) cur_PWM = (int16_t)-255*k;
  
  if ((cur_PWM < 0) && (get_direction() == 1)) {
    set_direction(0);
  } else
  if ((cur_PWM > 0) && (get_direction() == 0)) {
    set_direction(1);
  }

  uint8_t pwm_out = abs(cur_PWM / k);
  if (((set_speed < 0) && (digitalRead(end_stop_opened_pin) == LOW)) ||
      ((set_speed > 0) && (digitalRead(end_stop_closed_pin) == LOW)) ||
      (pwm_out < PWM_epsilon) ||
      (set_speed == 0))
  {
    set_pwm(0);
  } else {
    set_pwm(pwm_out);
  }

  last_encoder_value = cur_enc_value;
}

int16_t MotorControl::get_max_encoder() const
{
  return max_enc_value;
}

void MotorControl::set_max_encoder(const int16_t value)
{
  max_enc_value = value;
}

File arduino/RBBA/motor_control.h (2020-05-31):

#ifndef MOTOR_CONTROL_H
#define MOTOR_CONTROL_H

#include <stdint.h>
#include "text_buffer.h"

#define USE_TIMER2_OC2B

class Encoder;

class MotorControl {

const uint8_t PWM_epsilon        = 16;
const int8_t  encoder_reversal   =  1;
const uint8_t direction_reversal =  0;
const int8_t  speed_p            =  6;

const uint8_t position_epsilon = 5;
const uint8_t position_p       = 4;

const uint8_t motor_enable_pin; 
const uint8_t motor_direction_pin_A;
const uint8_t motor_direction_pin_B;
const uint8_t end_stop_opened_pin;
const uint8_t end_stop_closed_pin;

const uint16_t update_interval_uS;

Encoder &encoder;

int16_t last_encoder_value;
int16_t set_speed;
int16_t cur_PWM;
uint8_t cur_dir;

int16_t  set_position;
int16_t  max_speed;
int16_t  max_enc_value;

bool raw_mode;

public:
  const uint8_t home_PWM = 100;

  MotorControl(
    const uint8_t   en_pin, 
    const uint8_t   dir_pin_A, 
    const uint8_t   dir_pin_B,
    const uint8_t   es_opened_pin,
    const uint8_t   es_closed_pin,
    const uint16_t  upd_interval_uS,
    Encoder  &enc
  );

  void update();

  void hard_stop();

  void home();

  void calibrate();

  void move_const_time(const uint8_t pos, const uint16_t duration_mS);
  void move_const_speed(const uint8_t pos, const uint8_t speed);

  int16_t get_max_encoder() const;
  void set_max_encoder(const int16_t value);

  bool open_end_stop()  { return (digitalRead(end_stop_opened_pin) == LOW); } 
  bool close_end_stop() { return (digitalRead(end_stop_closed_pin) == LOW); } 

  void move_raw(const uint8_t pwm, const uint8_t dir);
  void zero_enc() { encoder.set_value(0); }
  void max_enc() { max_enc_value = encoder.get_value() * (int16_t)encoder_reversal; }

  int16_t get_encoder_value() { return encoder.get_value() * (int16_t)encoder_reversal; }

private:

  void set_pwm(const uint8_t pwm);

  void    set_direction(const uint8_t dir);
  uint8_t get_direction() const;
  
};



#endif

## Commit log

2020-05-31 added openscad geometry
    [bagmount.stl, bagmount_spacer.stl, bearingmount.stl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]
2020-05-31 added arduino code
2020-06-12 added overview comment to arduino project
